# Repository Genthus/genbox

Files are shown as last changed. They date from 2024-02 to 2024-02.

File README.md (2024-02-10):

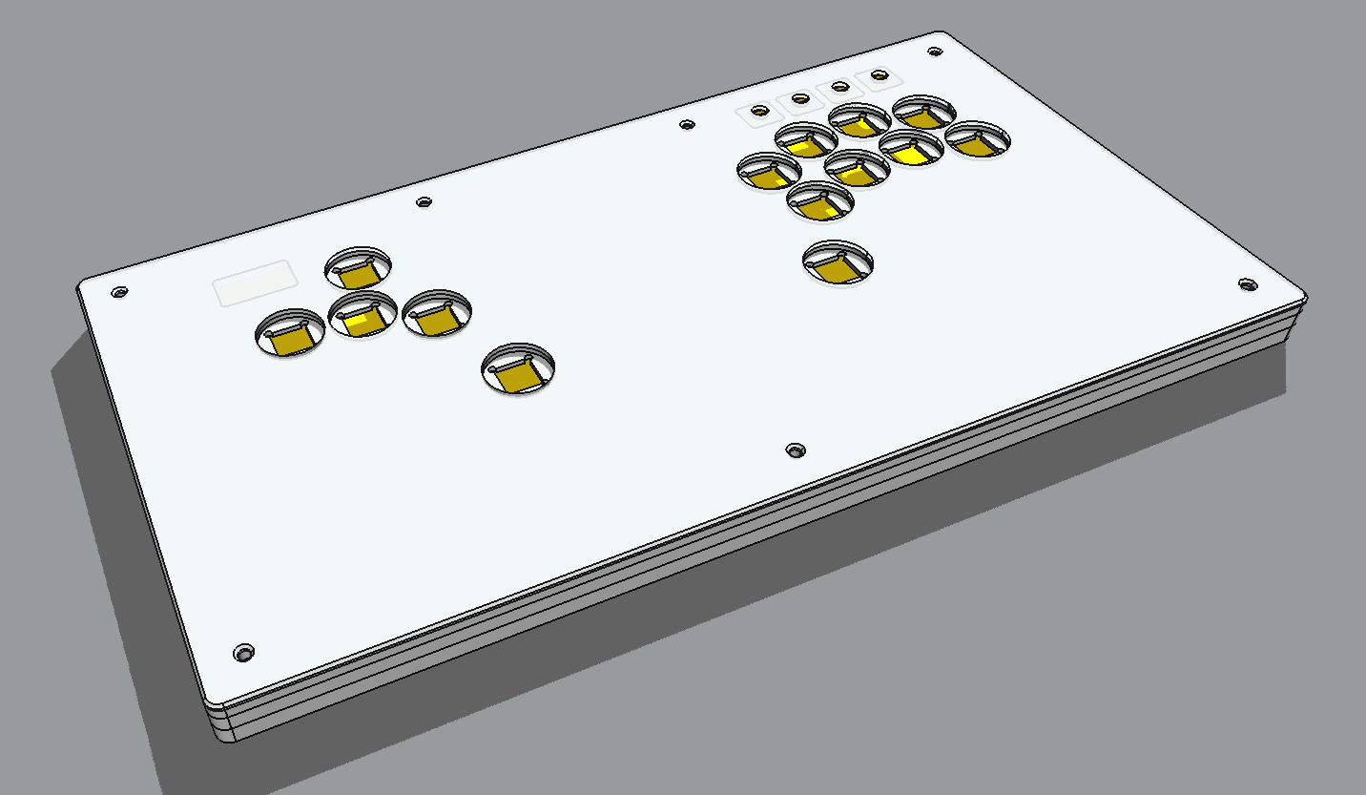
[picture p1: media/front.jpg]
front image

# GenBox
A leverless fightstick with ergonomic button placement as well as plenty of space for custom art!

# Sources

This project made use of the following:
- [Kicad](https://www.kicad.org/)
- [FreeCad Link](https://github.com/realthunder/FreeCAD)
- [Keebio-Parts.pretty](https://github.com/keebio/Keebio-Parts.pretty?tab=MIT-1-ov-file)
- [KiCad-SSD1306_OLED-0.91-128x32](https://github.com/MichMich/KiCad-SSD1306_OLED-0.91-128x32)
- [Tri-Hard-slab-v2](https://github.com/Rev1s10n/Tri-Hard-slab-v2?tab=readme-ov-file)

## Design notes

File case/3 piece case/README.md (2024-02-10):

Case made for CNC

# Required materials

- 7 M3 x 6mm x 4.2mm threaded heat inserts
- 7 M3 x 16mm hexagonal countersunk bolts
- 14 MX key switches
- 14 arcade MX button caps

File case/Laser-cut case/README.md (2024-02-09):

Case made for laser cutting tools

This case is currently UNTESTED and is here for development only, build at your own risk

# Required materials
Acrylic or interchangeable sheet of material in the following thicknesses:
- 2mm for cover
- 4mm for top and bottom
- 10mm for middle

- 7 M3 x 4mm x 4.2mm threaded heat inserts
- 7 M3 x 20mm button top bolt
- 14 MX key switches
- 14 arcade MX button caps

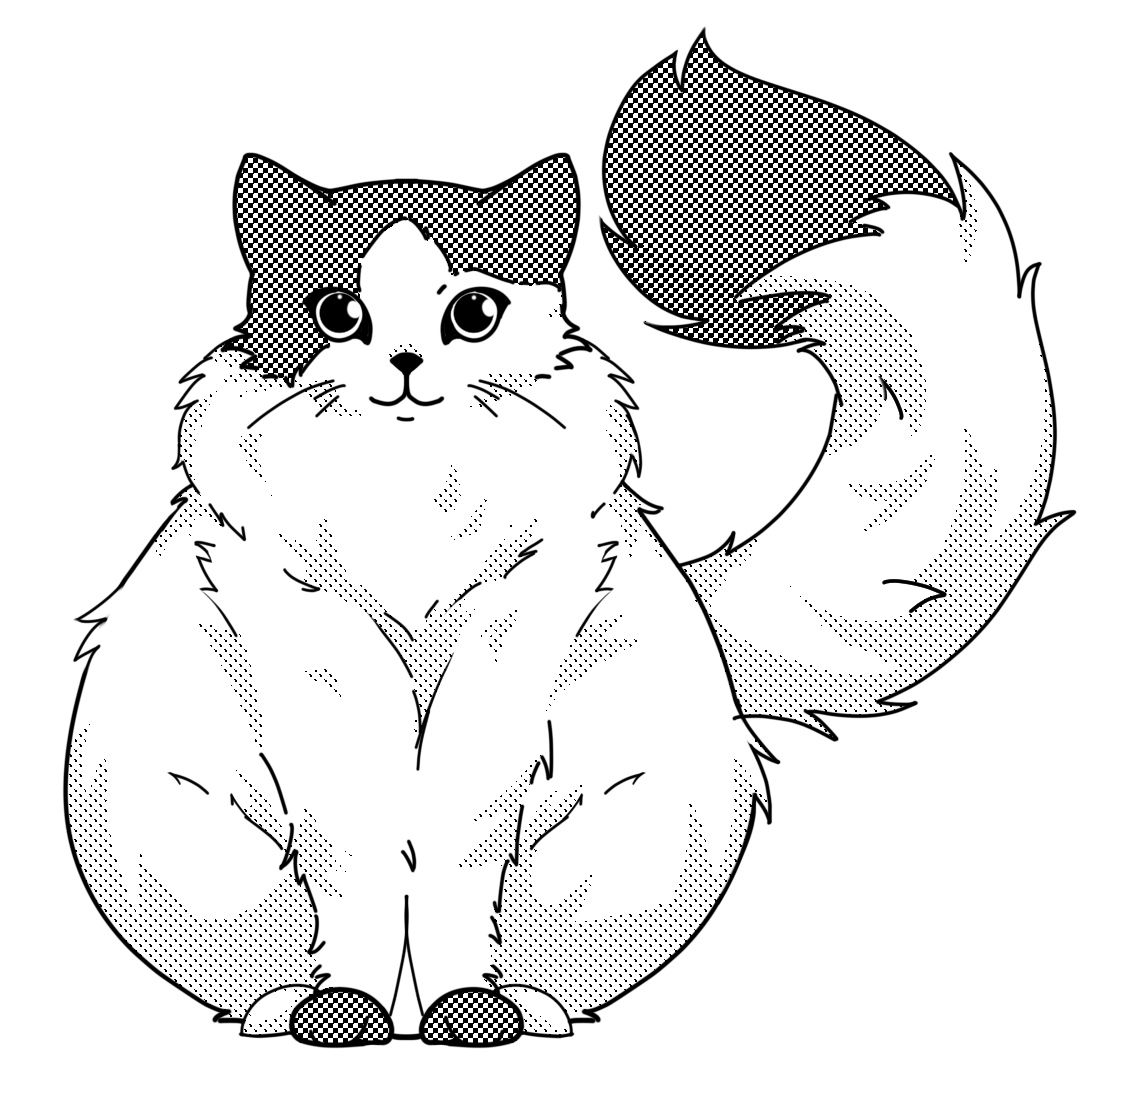
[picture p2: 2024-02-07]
media/haku.jpg

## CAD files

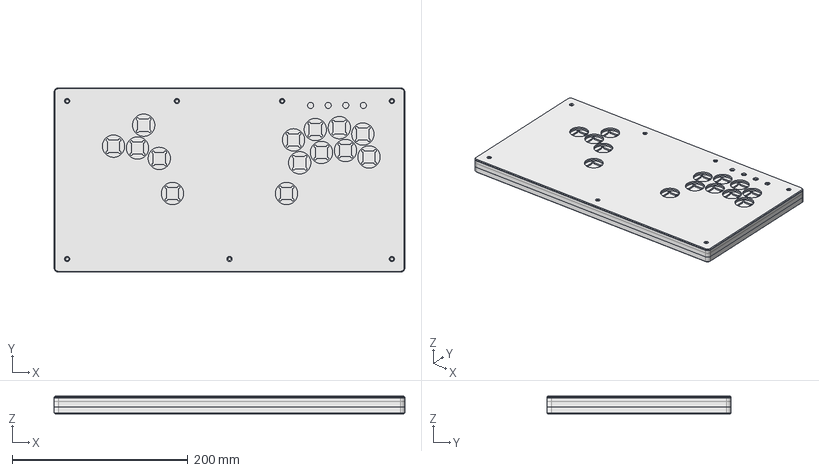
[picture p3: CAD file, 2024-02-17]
case/3 piece case/genboxFull.FCStd
400.0 x 210.0 x 20.0 mm
cover
bottom
middle

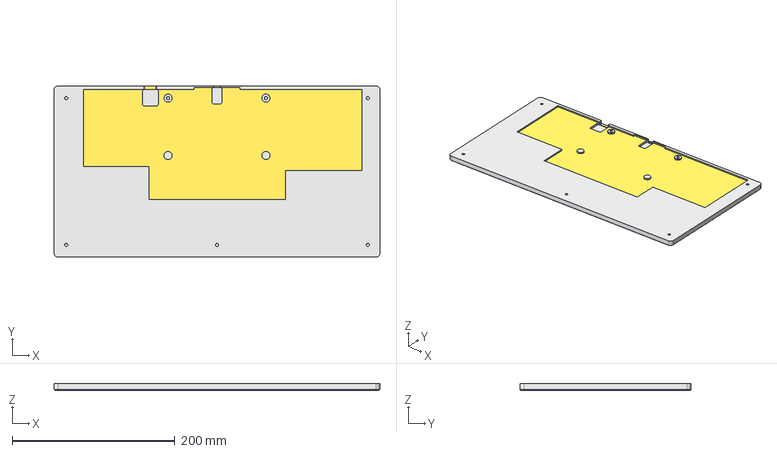
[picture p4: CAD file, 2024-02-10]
case/3 piece case/genboxFull-bottom.step
400.0 x 210.0 x 8.00 mm

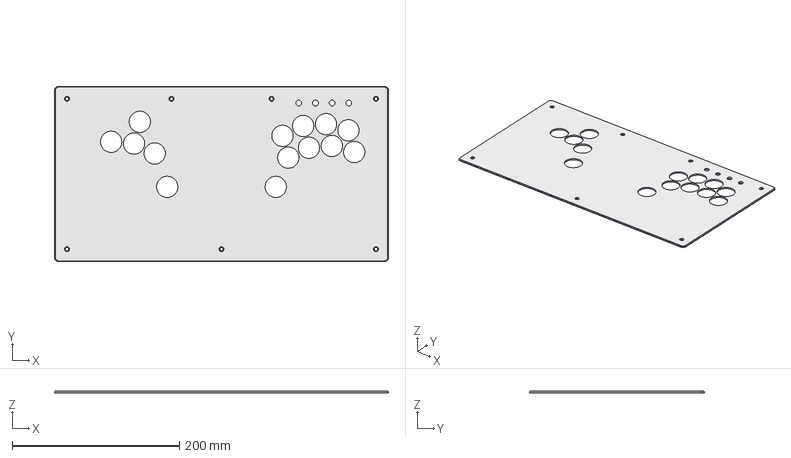
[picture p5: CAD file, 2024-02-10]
case/3 piece case/genboxFull-cover.step
400.0 x 210.0 x 2.00 mm

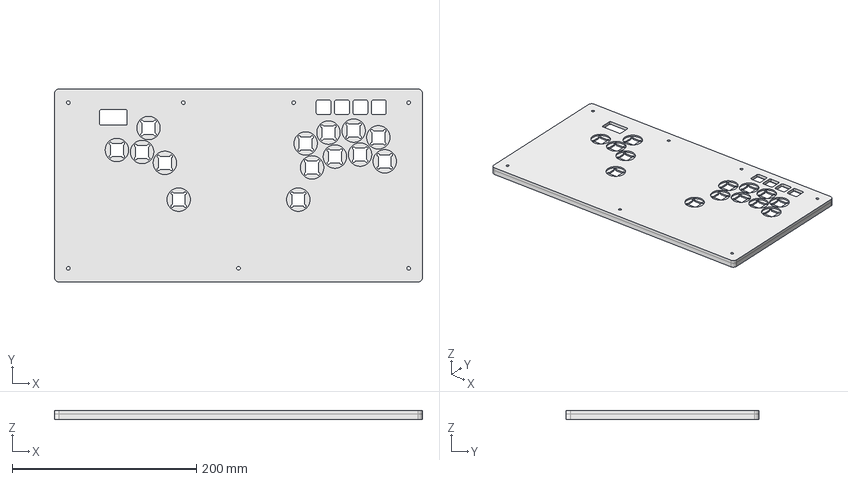
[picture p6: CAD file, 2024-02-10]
case/3 piece case/genboxFull-middle.step
400.0 x 210.0 x 10.0 mm

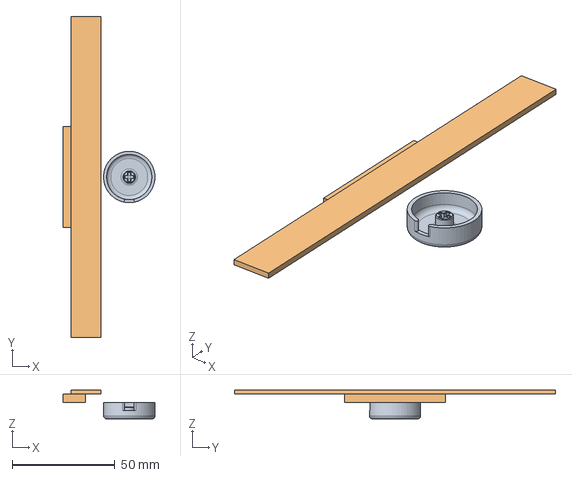
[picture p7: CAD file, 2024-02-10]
button/button.FCStd
44.7 x 156.1 x 14.0 mm
MX button
top board

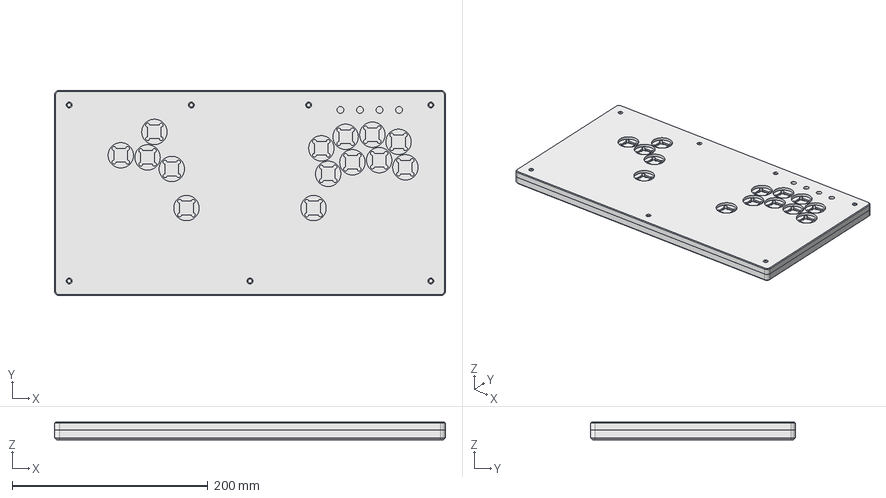
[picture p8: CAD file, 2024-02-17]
case/2 piece case/genbox.FCStd
400.0 x 210.0 x 18.0 mm
Top
Case

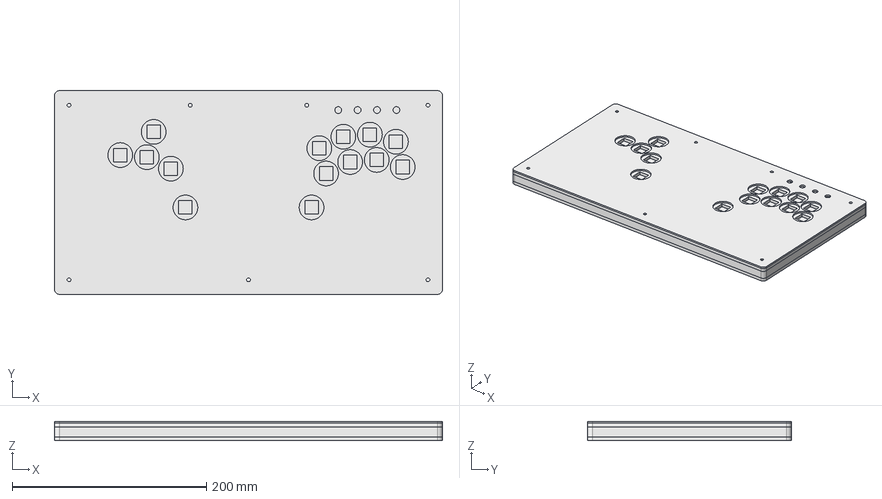
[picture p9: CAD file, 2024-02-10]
case/Laser-cut case/genboxSimple.FCStd
400.0 x 210.0 x 20.0 mm
top
bottom
PCB
cover
middle

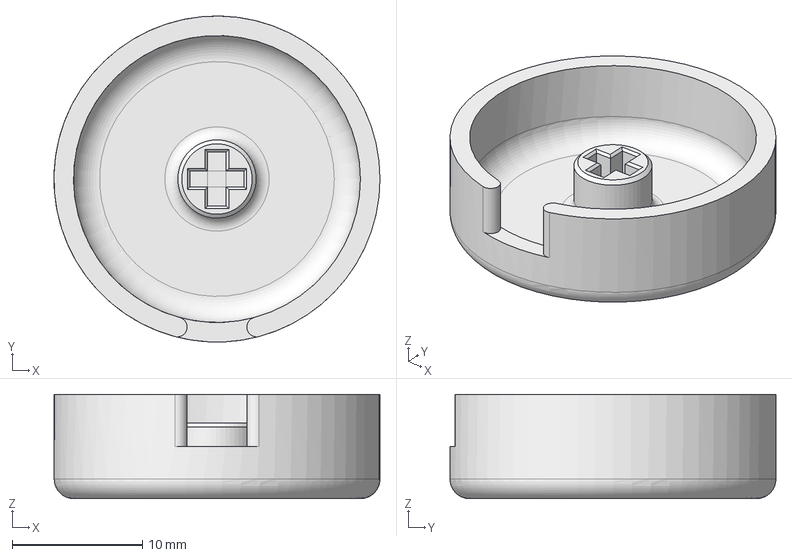
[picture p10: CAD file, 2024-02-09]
button/button-MX button.step
25.0 x 25.0 x 8.00 mm

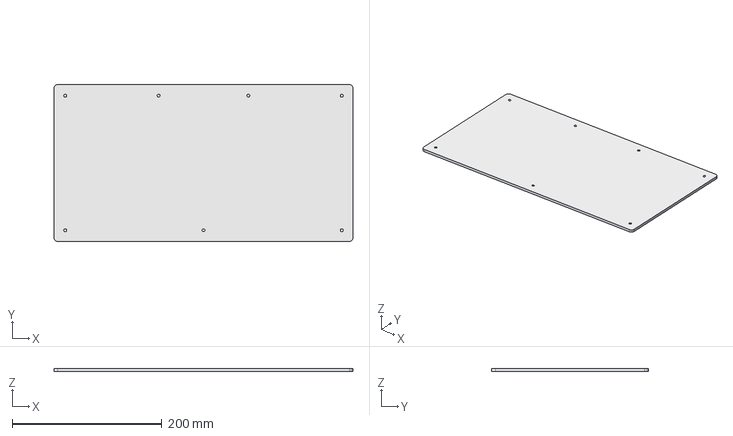
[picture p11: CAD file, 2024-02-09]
case/Laser-cut case/genboxSimple-bottom.step
400.0 x 210.0 x 4.00 mm

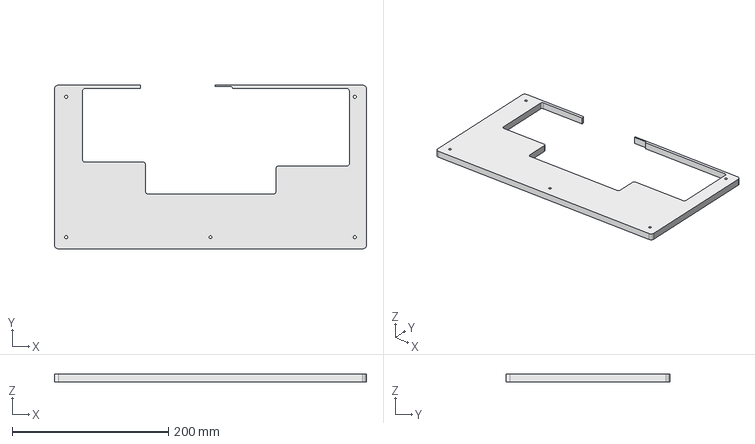
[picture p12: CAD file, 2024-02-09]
case/Laser-cut case/genboxSimple-middle.step
400.0 x 210.0 x 10.0 mm

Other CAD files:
case/full case/genbox-Case.step
case/2 piece case/genbox-Top.step
case/2 piece case/genbox-Case.step
case/Laser-cut case/genboxSimple-cover.step
case/Laser-cut case/genboxSimple-top.step

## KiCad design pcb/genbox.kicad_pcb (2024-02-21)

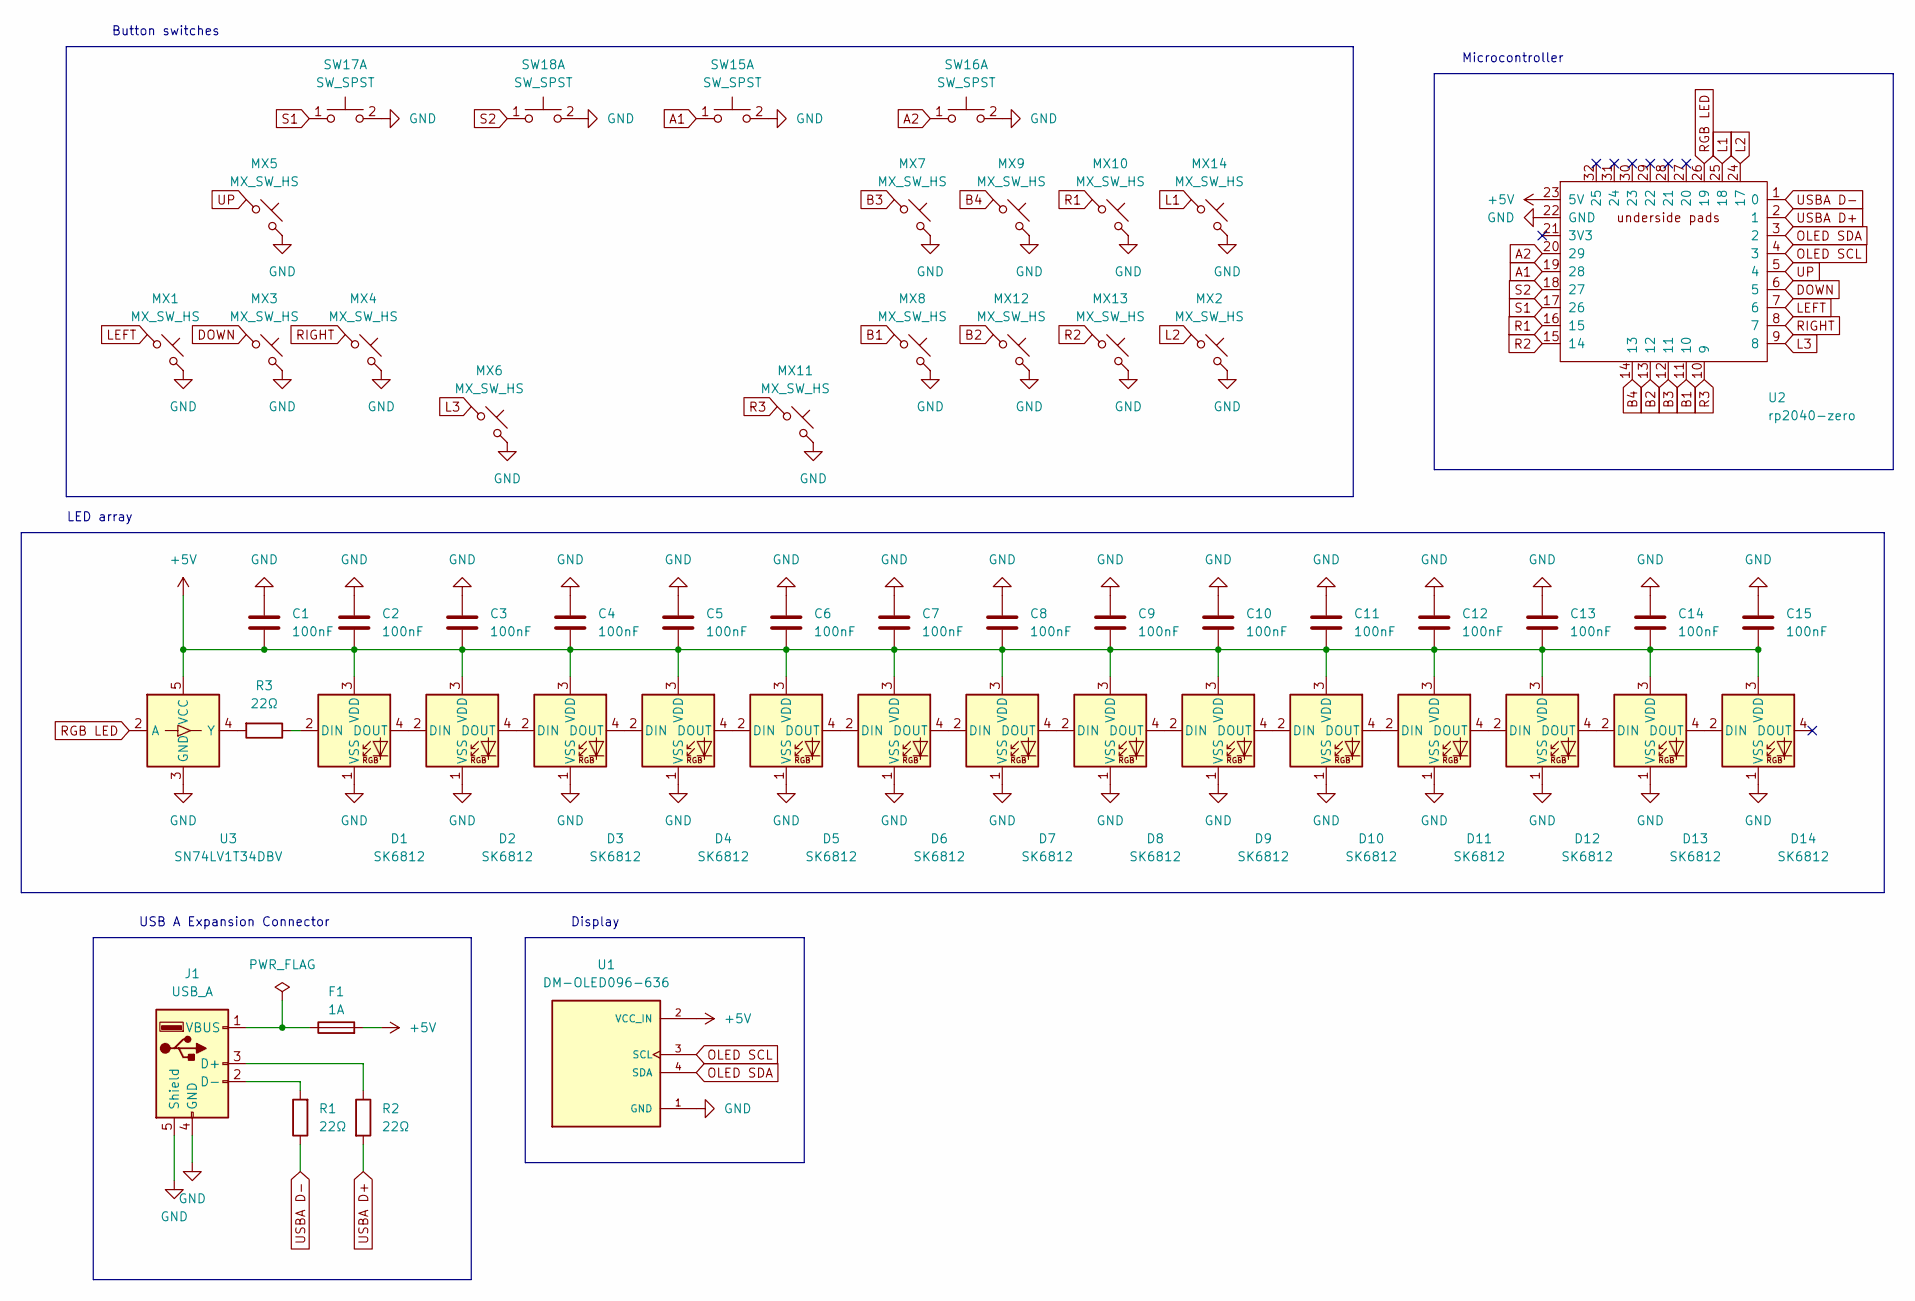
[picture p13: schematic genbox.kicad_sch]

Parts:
C1, C2, C3, C4, C5, C6, C7, C8, C9, C10, C11, C12, C13, C14, C15: 100nF; C_0805_2012Metric_Pad1.18x1.45mm_HandSolder; LCSC Part # C2169363
D1, D2, D3, D4, D5, D6, D7, D8, D9, D10, D11, D12, D13, D14: SK6812; SK6812-MINI-E_MX; LCSC Part # C5149201
F1: 1A; Fuse_0805_2012Metric_Pad1.15x1.40mm_HandSolder; LCSC Part # C116170
J1: USB_A; USB_A_Receptacle_GCT_USB1046; LCSC Part # C2689981
MX1, MX2, MX3, MX4, MX5, MX6, MX7, MX8, MX9, MX10, MX11, MX12, MX13, MX14: MX_SW_HS; SW_MX_HS_1u; LCSC Part # C5184526
R1, R2, R3: 22Ω; R_0603_1608Metric_Pad0.98x0.95mm_HandSolder; LCSC Part # C23345
SW15, SW16, SW17, SW18: SW_SPST; SW_PUSH-12mm_centered; LCSC Part # C455212
U1: DM-OLED096-636; MODULE_DM-OLED096-636; PARTREV 2018-09-10; LCSC Part # C5248080
U2: rp2040-zero; rp2040-zero-smd-pads; LCSC Part # C5350143
U3: SN74LV1T34DBV; SOT-23-5; LCSC Part # C100024

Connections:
+5V: C1.2, C2.2, C3.2, C4.2, C5.2, C6.2, C7.2, C8.2, C9.2, C10.2, C11.2, C12.2, C13.2, C14.2, C15.2, D1.3 (VDD), D2.3 (VDD), D3.3 (VDD), D4.3 (VDD), D5.3 (VDD), D6.3 (VDD), D7.3 (VDD), D8.3 (VDD), D9.3 (VDD), D10.3 (VDD), D11.3 (VDD), D12.3 (VDD), D13.3 (VDD), D14.3 (VDD), F1.2, U1.2 (VCC_IN), U2.23 (5V), U3.5 (VCC)
A1: SW15.1 (C), U2.19 (28)
A2: SW16.1 (C), U2.20 (29)
B1: MX8.1, U2.11 (10)
B2: MX12.1, U2.13 (12)
B3: MX7.1, U2.12 (11)
B4: MX9.1, U2.14 (13)
DOWN: MX3.1, U2.6 (5)
GND: C1.1, C2.1, C3.1, C4.1, C5.1, C6.1, C7.1, C8.1, C9.1, C10.1, C11.1, C12.1, C13.1, C14.1, C15.1, D1.1 (VSS), D2.1 (VSS), D3.1 (VSS), D4.1 (VSS), D5.1 (VSS), D6.1 (VSS), D7.1 (VSS), D8.1 (VSS), D9.1 (VSS), D10.1 (VSS), D11.1 (VSS), D12.1 (VSS), D13.1 (VSS), D14.1 (VSS), J1.4 (GND), J1.5 (Shield), MX1.2, MX2.2, MX3.2, MX4.2, MX5.2, MX6.2, MX7.2, MX8.2, MX9.2, MX10.2, MX11.2, MX12.2, MX13.2, MX14.2, SW15.2 (D), SW16.2 (D), SW17.2 (D), SW18.2 (D), U1.1 (GND), U2.22 (GND), U2.33 (GND), U3.3 (GND)
L1: MX14.1, U2.25 (18)
L2: MX2.1, U2.24 (17)
L3: MX6.1, U2.9 (8)
LEFT: MX1.1, U2.7 (6)
unnamed: D1.2 (DIN), R3.1
unnamed: D1.4 (DOUT), D2.2 (DIN)
unnamed: D2.4 (DOUT), D3.2 (DIN)
unnamed: D3.4 (DOUT), D4.2 (DIN)
unnamed: D4.4 (DOUT), D5.2 (DIN)
unnamed: D5.4 (DOUT), D6.2 (DIN)
unnamed: D6.4 (DOUT), D7.2 (DIN)
unnamed: D7.4 (DOUT), D8.2 (DIN)
unnamed: D8.4 (DOUT), D9.2 (DIN)
unnamed: D9.4 (DOUT), D10.2 (DIN)
unnamed: D10.4 (DOUT), D11.2 (DIN)
unnamed: D11.4 (DOUT), D12.2 (DIN)
unnamed: D12.4 (DOUT), D13.2 (DIN)
unnamed: D13.4 (DOUT), D14.2 (DIN)
unnamed: J1.3 (D+), R2.1
unnamed: J1.2 (D-), R1.2
unnamed: F1.1, J1.1 (VBUS)
unnamed: R3.2, U3.4 (Y)
OLED SCL: U1.3 (SCL), U2.4 (3)
OLED SDA: U1.4 (SDA), U2.3 (2)
R1: MX10.1, U2.16 (15)
R2: MX13.1, U2.15 (14)
R3: MX11.1, U2.10 (9)
RGB LED: U2.26 (19), U3.2 (A)
RIGHT: MX4.1, U2.8 (7)
S1: SW17.1 (C), U2.17 (26)
S2: SW18.1 (C), U2.18 (27)
UP: MX5.1, U2.5 (4)
USBA D+: R2.2, U2.2 (1)
USBA D-: R1.1, U2.1 (0)

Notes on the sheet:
Microcontroller
Display
LED array
USB A Expansion Connector
Button switches

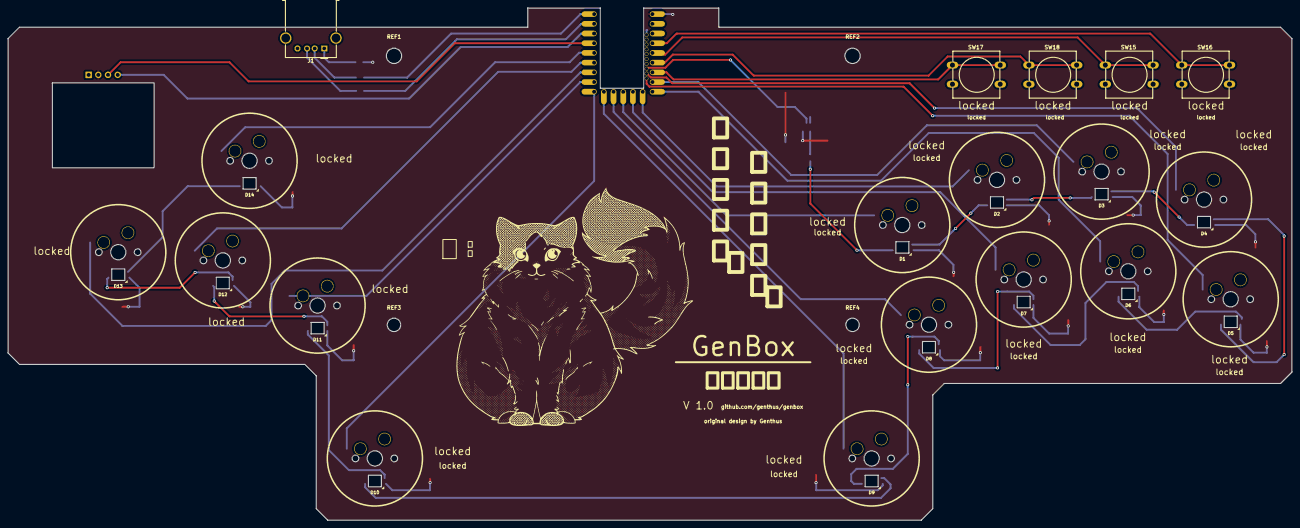
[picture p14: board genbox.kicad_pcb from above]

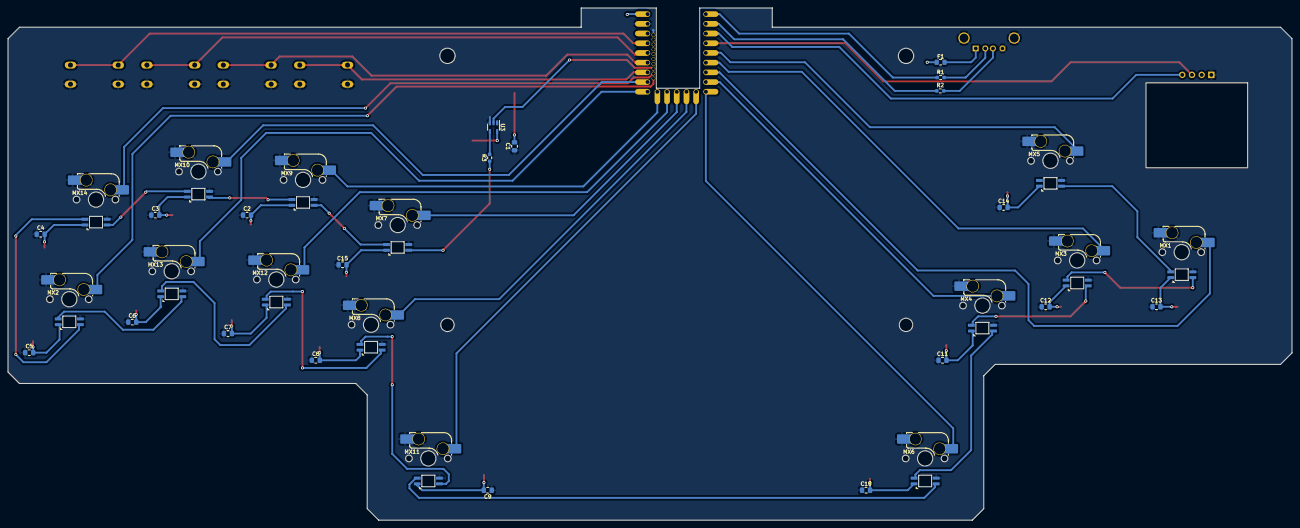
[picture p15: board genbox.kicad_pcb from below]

Board: 2 copper layers, 336.0 x 134.0 mm, 59 parts (35 on the bottom side), 43 nets.

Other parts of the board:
REF1, REF2: MountingHole_4mm
REF3, REF4: MountingHole_3.5mm

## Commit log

2024-02-03 removed release and compiled files
    [genBox2-Case.step, genBox2-top.step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]
2024-02-03 removed gerber zip
2024-02-04 fixed gitignore
    [genbox.kicad_sch]
2024-02-04 doubled trace width
    [genbox.kicad_pcb]
2024-02-04 changed freecad filename
    [genBox2.FCStd, genbox.FCStd]
2024-02-04 pcb dimension changes
    [genbox.kicad_pcb]
2024-02-04 moved drill holes
    [genbox.FCStd]
2024-02-06 rework p1
    [genbox.FCStd, genbox.kicad_pcb, genbox.kicad_sch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]
2024-02-06 converted to freecad link branch
    [genbox.kicad_sch, genbox3.FCStd]
2024-02-07 pcb rework complete
    [genbox.kicad_pcb, genbox.kicad_sch]
2024-02-07 pcb handsolder adjustments
    [genbox.kicad_pcb]
2024-02-07 reworked 5+v traces
    [genbox.kicad_pcb]
2024-02-07 added mounting holes
    [genbox.kicad_pcb, genbox3.FCStd]
2024-02-07 mounting hole sketch
    [genbox3.FCStd]
2024-02-07 usb a connection switch
    [genbox.kicad_pcb, genbox.kicad_sch]
2024-02-07 fixed usb position
    [genbox3.FCStd]
2024-02-07 thickened case, fixed bottom chamfer
    [genbox.FCStd, genbox2.FCStd, genbox3.FCStd]
2024-02-07 moved case files
    [genbox-Case.step, genbox-Top.step, genbox.FCStd]
2024-02-07 added simple case
    [genboxSimple-Bottom.step, genboxSimple-middle.step, genboxSimple-top.step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]
2024-02-07 pcb adjustments and readme
    [genbox.kicad_pcb]
2024-02-08 fixed bad geometry
    [genboxSimple.FCStd]
2024-02-09 added button
    [button-MX button.step, button.FCStd]
2024-02-09 improved button design
    [button.FCStd]
2024-02-09 added inside fillet to button
    [button-MX button.step, button.FCStd]
2024-02-09 added case readme, changed screw size, removed svg files
    [genboxSimple-Bottom.step, genboxSimple-cover.step, genboxSimple-middle.step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]
2024-02-10 model updates
    [button.FCStd, genbox.FCStd, genboxSimple.FCStd]
2024-02-10 added case version 2
    [genboxFull-bottom.step, genboxFull-cover.step, genboxFull-middle.step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]
2024-02-10 changed picture
    [genboxFull.FCStd]
2024-02-10 changed folder names
    [genbox-Case.step, genbox-Top.step, genbox.FCStd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]
2024-02-10 more name changes
    [genbox-Case.step, genbox-Top.step, genbox.FCStd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]
2024-02-17 updated names and reworked 2 piece case
    [genbox-Case.step, genbox-Top.step, genbox.FCStd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]
2024-02-21 increased OLED hole, enlarged rp2040 pads
    [genbox.kicad_pcb]
2024-02-21 fixed kicad footprint path
